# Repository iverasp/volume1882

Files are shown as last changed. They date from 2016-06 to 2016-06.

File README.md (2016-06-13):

## Storing the wiper positions

The DS1882 has an internal EEPROM which can store the wiper positions. However, it will write to the EEPROM on all volume changes, which will quickly wear out the memory.

We therefore store the wiper positions in the Atmega328p EEPROM instead. This EEPROM is said to survive 100 000 writes. To avoid writing to the EEPROM on all volume changes, we wait until the user has let the rotary encoder untouched for 3 seconds.
At an estimate of 10 volume changes per day in average, this lets the EEPROM survive for at least 27 years.

## DS1882 address

A2, A1 and A0 on the DS1882 are tied to ground.
The address of the device therefore becomes 40 (00101000 in binary).

## BOM

All passive SMD parts are of package 1206

Electrolytic capacitors: 2x0.1uF + 1uF + 10uF. Designed for 5mm diameter (Nichicon KW/FG).  
SMD capacitors: 3x0.1uF ceramic  
SMD resistors: 560R, 120R, 240R, 1k1, 2x4k7, 3x10k, 3x470R  
Voltage regulators: LM337 and LM317, SOT-223 packages  
Diodes: 1N4002 through hole  
ICs: DS1882 SOIC16 and ATmega328p TQFP-32  
Male headers: 1pcs 1x5 pins, 2pcs 1x4 pins, 4pcs 1x3 pins, 1pcs 1x2 pins, 1pcs 2x3 pins

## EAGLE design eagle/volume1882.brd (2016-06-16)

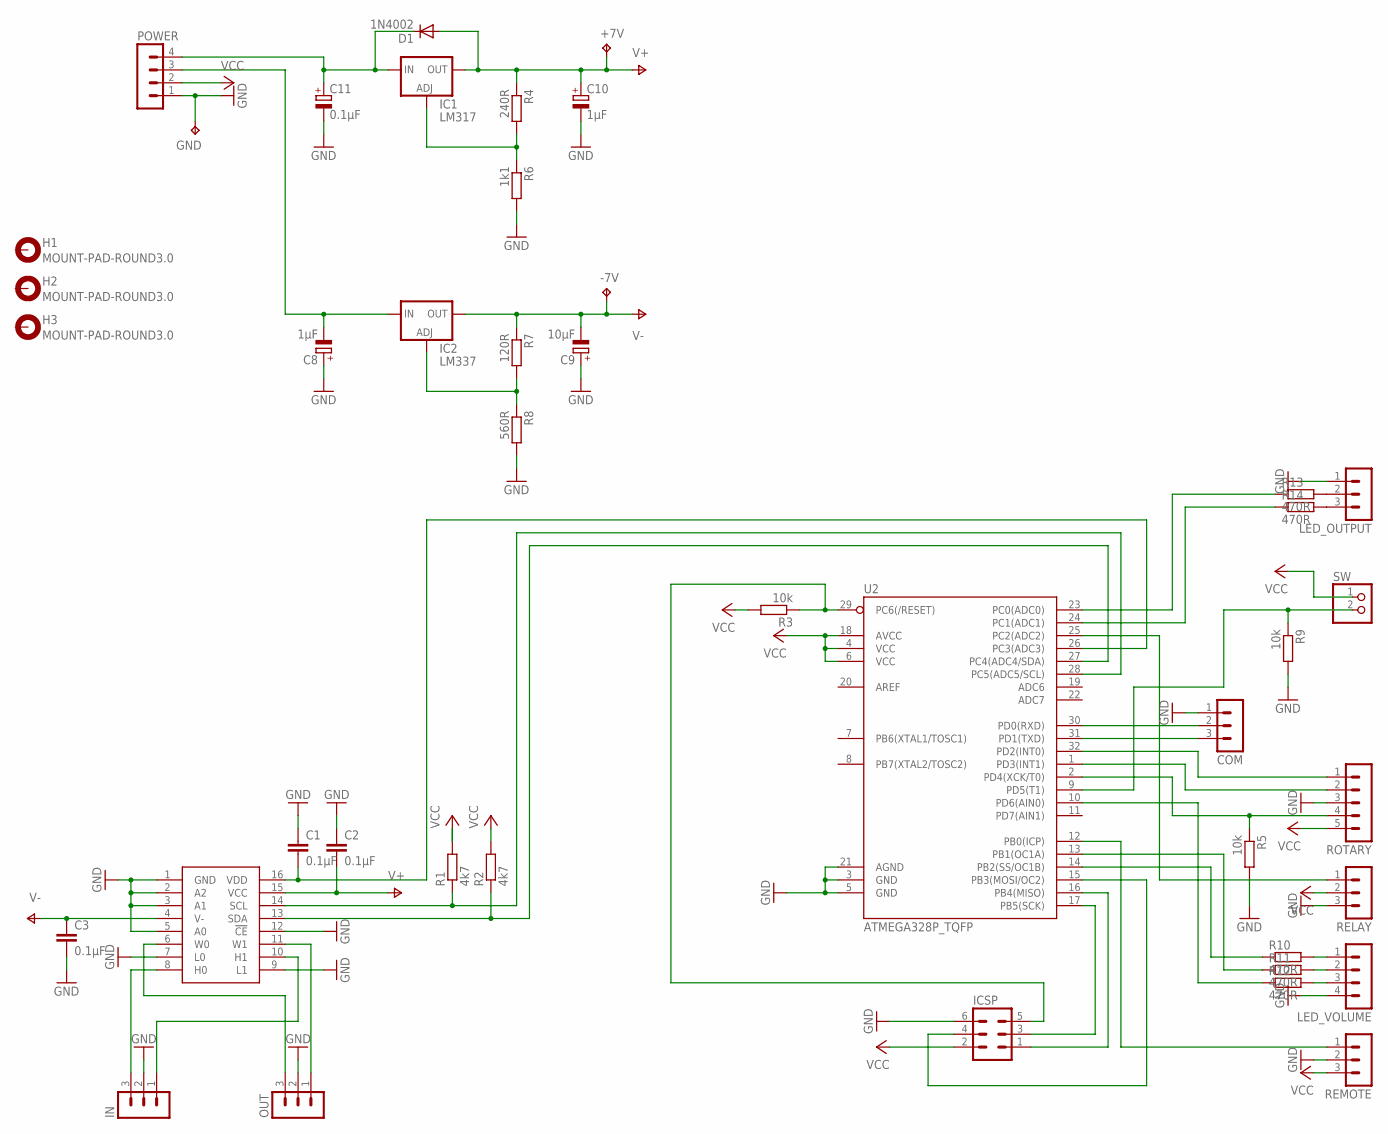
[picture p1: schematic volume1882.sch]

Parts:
+7V: TPTP12SQ; TP12SQ
-7V: TPTP12SQ; TP12SQ
C1, C2, C3: 0.1µF; C1206
C8, C10: 1µF; E2-5
C9: 10µF; E2-5
C11: 0.1µF; E2-5
COM: MA03-1
D1: 1N4002; DO41-10
GND: TPTP12SQ; TP12SQ
H1, H2, H3: MOUNT-PAD-ROUND3.0; 3,0-PAD
IC1: LM317; SOT223
IC2: LM337; SOT223
ICSP: MA03-2
IN: MA03-1
LED_OUTPUT: MA03-1
LED_VOLUME: MA04-1
OUT: MA03-1
POWER: MA04-1
R1, R2: 4k7; R1206
R3, R5, R9: 10k; R1206
R4: 240R; R1206
R6: 1k1; R1206
R7: 120R; R1206
R8: 560R; R1206
R10, R11, R12, R13, R14: 470R; R1206
RELAY: MA03-1
REMOTE: MA03-1
ROTARY: MA05-1
SW: PINHD-1X2; 1X02
U1: DS1882; SO16
U2: ATMEGA328P_TQFP; TQFP32-08

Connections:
GND: C1.1, C2.1, C3.2, C8.+, C9.+, C10.-, C11.-, COM.1, GND.TP, ICSP.6, IN.2, LED_OUTPUT.1, LED_VOLUME.4, OUT.2, POWER.1, R5.2, R6.2, R8.2, R9.2, RELAY.3, REMOTE.2, ROTARY.3, U1.1 (GND), U1.2 (A2), U1.3 (A1), U1.5 (A0), U1.7 (L0), U1.9 (L1), U1.12 (!CE), U2.3 (GND), U2.5 (GND), U2.21 (AGND)
unnamed: ICSP.5, R3.1, U2.29 (PC6(/RESET))
unnamed: ICSP.1, U2.16 (PB4(MISO))
unnamed: ICSP.3, U2.17 (PB5(SCK))
unnamed: ICSP.4, U2.15 (PB3(MOSI/OC2))
unnamed: R1.1, U1.14 (SCL), U2.28 (PC5(ADC5/SCL))
unnamed: R2.1, U1.13 (SDA), U2.27 (PC4(ADC4/SDA))
unnamed: COM.3, U2.31 (PD1(TXD))
unnamed: COM.2, U2.30 (PD0(RXD))
unnamed: ROTARY.1, U2.32 (PD2(INT0))
unnamed: ROTARY.2, U2.1 (PD3(INT1))
unnamed: R5.1, ROTARY.4, U2.2 (PD4(XCK/T0))
unnamed: C1.2, U1.16 (VDD), U2.26 (PC3(ADC3))
unnamed: R11.1, U2.13 (PB1(OC1A))
unnamed: R10.1, U2.14 (PB2(SS/OC1B))
unnamed: R12.1, U2.10 (PD6(AIN0))
unnamed: IN.3, U1.8 (H0)
unnamed: IN.1, U1.10 (H1)
unnamed: OUT.3, U1.6 (W0)
unnamed: OUT.1, U1.11 (W1)
unnamed: C11.+, D1.C, IC1.3 (IN), POWER.4
unnamed: C8.-, IC2.2 (IN), POWER.3
unnamed: IC1.1 (ADJ), R4.2, R6.1
unnamed: R9.1, SW.2, U2.9 (PD5(T1))
unnamed: IC2.1 (ADJ), R7.2, R8.1
unnamed: RELAY.1, U2.25 (PC2(ADC2))
unnamed: LED_VOLUME.1, R10.2
unnamed: LED_VOLUME.2, R11.2
unnamed: LED_VOLUME.3, R12.2
unnamed: R13.1, U2.23 (PC0(ADC0))
unnamed: R14.1, U2.24 (PC1(ADC1))
unnamed: LED_OUTPUT.2, R13.2
unnamed: LED_OUTPUT.3, R14.2
unnamed: REMOTE.1, U2.12 (PB0(ICP))
V+: +7V.TP, C2.2, C10.+, D1.A, IC1.4 (OUT), R4.1, U1.15 (VCC)
V-: -7V.TP, C3.1, C9.-, IC2.3 (OUT), R7.1, U1.4 (V-)
VCC: ICSP.2, POWER.2, R1.2, R2.2, R3.2, RELAY.2, REMOTE.3, ROTARY.5, SW.1, U2.4 (VCC), U2.6 (VCC), U2.18 (AVCC)

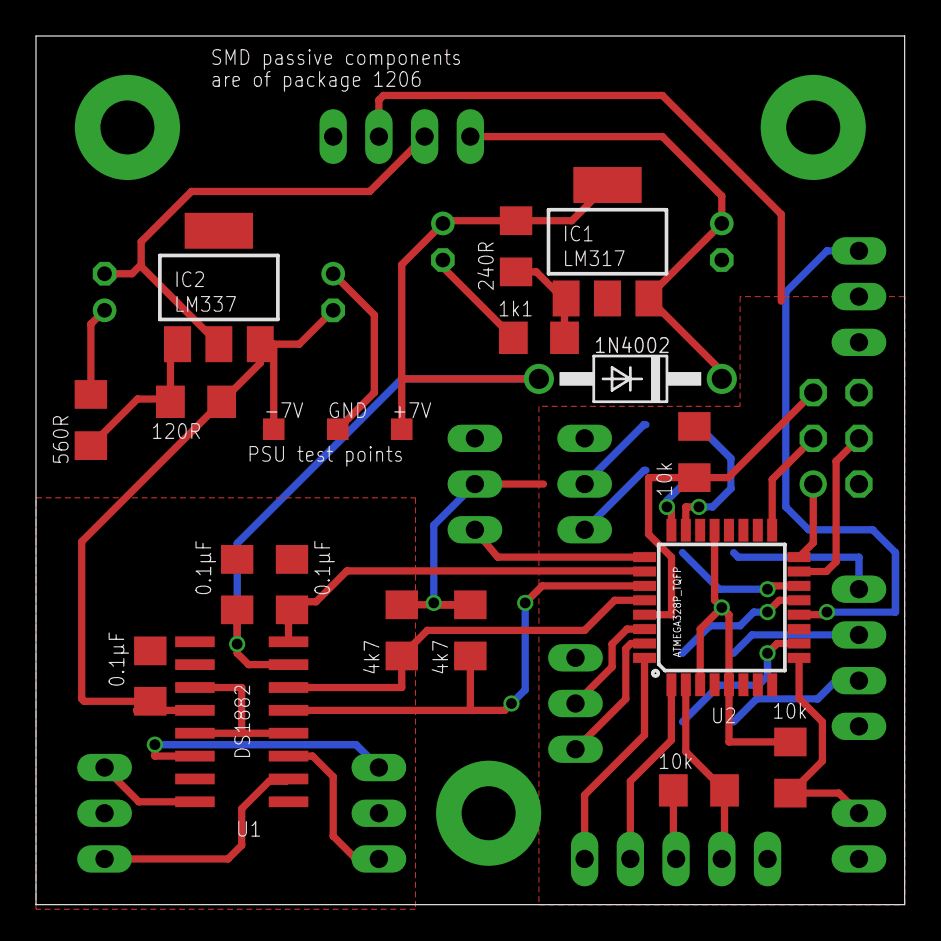
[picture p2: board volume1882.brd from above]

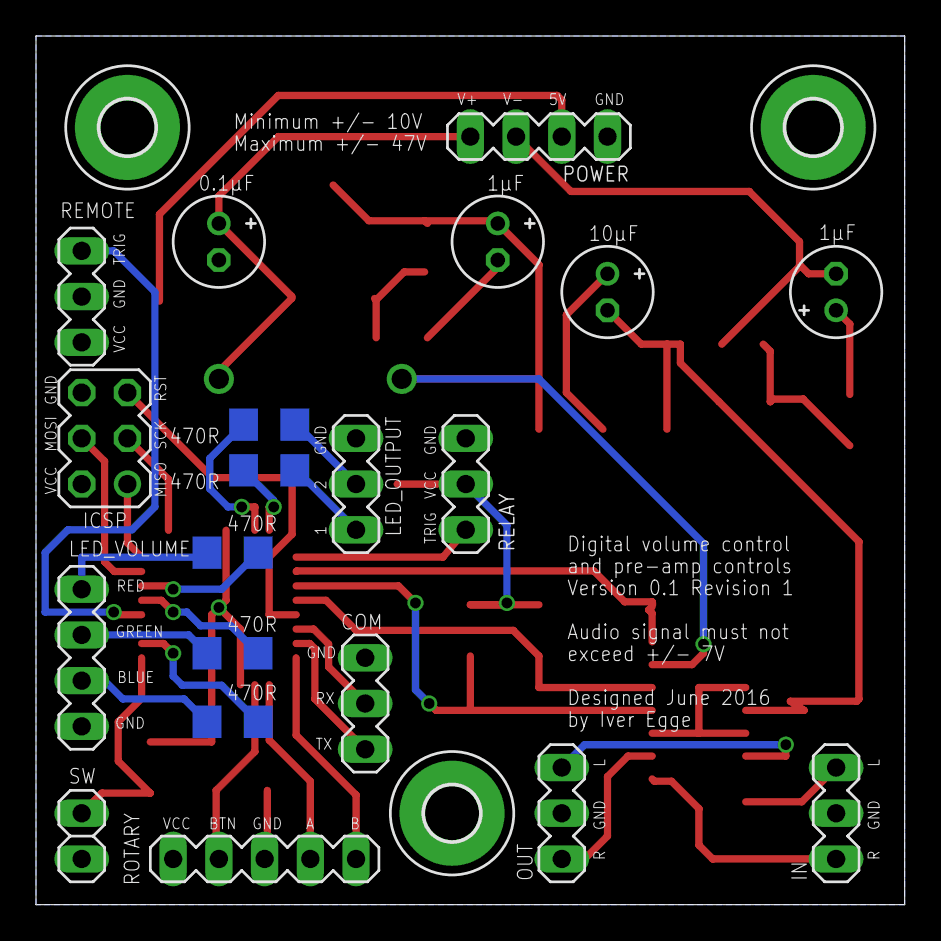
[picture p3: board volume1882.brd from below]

Board: 2 copper layers, 48.3 x 48.3 mm, 43 parts (23 on the bottom side), 37 nets.

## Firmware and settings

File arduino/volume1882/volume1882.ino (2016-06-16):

#include <Wire.h>
#include <Encoder.h>
#include <EEPROM.h>

const short red = 9; // pwm
const short green = 10; // pwm
const short potVdd = A3;
const short encA = 2; // interrupt
const short encB = 3; // interrupt
const int encMax = 62;
const short encDiv = 4; // encoder counts 4 steps per click
Encoder encoder(encB, encA);

const int muteButtonPin = 4;
int muteButtonState;
int lastMuteButtonState = LOW;
long lastMuteDebounceTime = 0;
long debounceDelay = 50;

const int outputSelectPin = 7;
int outputSelectState;
int lastOutputSelectState;
long lastOutputSelectDebounceTime = 0;
const int outputRelayPin = 8;
const int headphonesOutput = 0;
const int powerampOutput = 1;

bool mute = false;
byte muteAddress = 0;
byte attenuationAddress = 1;
byte headphonesMuteAddress = 0;
byte headphonesAttenuationAddress = 1;
byte powerampMuteAddress = 2;
byte powerampAttenuationAddress = 3;
byte lastAttenuation;
byte muteAttenuation = 63;
byte fadeStart = 50;
byte fadeStep = fadeStart;
byte fadeAmount = 5;

// A0, A1, A2 of DS1882 are shorted to ground
const byte potAddress = B0101000;
const byte potConfig = B10000110; // volatile memory, zero-crossing detection, 63 positions 

unsigned long attenuationChangeTimer = 0;
unsigned long startTime = 0;
unsigned long attenuationChangeTimeout = 2000;
byte lastStoredAttenuation = 0;

void setup() {
  pinMode(red, OUTPUT);
  pinMode(green, OUTPUT);
  delay(300); // wait for Vcc on DS1882 to stabilize
  pinMode(potVdd, OUTPUT);
  digitalWrite(potVdd, HIGH);
  
  //Serial.begin(9600);
  //Serial.println("Starting execution");
  
  Wire.begin();
  //TWBR = 12; // Sets i2c speed to 400kHz (max)
  Wire.beginTransmission(potAddress);
  byte error = Wire.endTransmission();
  if (error == 0) {
    //Serial.print("DS1882 found at address ");
    //Serial.println(potAddress);
  }
  Wire.requestFrom(potAddress, 3); // read pot0, pot1 and config
  byte pot1, pot2, conf;
  while (Wire.available()) {
    pot1 = Wire.read();
    pot2 = Wire.read();
    conf = Wire.read();
  }
  if (conf != potConfig) {
    //Serial.println("DS1882 config is incorrect. Uploading correct config...");
    Wire.beginTransmission(potAddress);
    Wire.write(potConfig);
    byte error = Wire.endTransmission();
    //Serial.println(error);
  }

  pinMode(outputSelectPin, INPUT);
  int lastOutputSelectState = digitalRead(outputSelectPin);
  pinMode(outputRelayPin, OUTPUT);
  selectOutput(digitalRead(outputSelectPin));
}

void loop() {
  if (!mute) {
    long value = readEncoder();
    analogWrite(red, ((((value+2) * 4) - 255)*-1)+1);
    analogWrite(green, value * 4);
    if (value != lastAttenuation) {
      adjustAttenuation(value);
      attenuationChangeTimer = millis();
    }
    if (millis() - attenuationChangeTimer > attenuationChangeTimeout) {
      storeAttenuation(value);
    }
  } else {
    analogWrite(red, fadeStep);
    analogWrite(green, (fadeStep - 255)*-1);
    fadeStep += fadeAmount;
    if (fadeStep < fadeStart || fadeStep > 200) {
      fadeAmount = -fadeAmount;
    }
    delay(30);
  }
  readMuteButton();
  readToggleSwitch();
}

long readEncoder() {
  long value = encoder.read();
  if (value > encMax * encDiv) {
    encoder.write(encMax * encDiv);
    return encMax;
  }
  if (value < 0) {
    encoder.write(0);
    return 0;
  }
  return value / encDiv;
}

void readMuteButton() {
  int reading = digitalRead(muteButtonPin);
  if (reading != lastMuteButtonState) {
    lastMuteDebounceTime = millis();
  }
  if ((millis() - lastMuteDebounceTime) > debounceDelay) {
    if (reading != muteButtonState) {
      muteButtonState = reading;
      if (muteButtonState == HIGH) {
        toggleMute();
      }
    }
  }
  lastMuteButtonState = reading;
}

void readToggleSwitch() {
  int reading = digitalRead(outputSelectPin);
  if (reading != lastOutputSelectState) {
    lastOutputSelectDebounceTime = millis();
  }
  if ((millis() - lastOutputSelectDebounceTime) > debounceDelay) {
    if (reading != outputSelectState) {
      outputSelectState = reading;
      selectOutput(outputSelectState);
    }
  }
  lastOutputSelectState = reading;
}

void toggleMute() {
  mute = !mute;
  if (EEPROM.read(muteAddress) != mute) {
    EEPROM.write(muteAddress, mute);
  }
  fadeStep = fadeStart;
  if (mute) {
    storeAttenuation(readEncoder());
    adjustAttenuation(muteAttenuation);
  } else {
    encoder.write(lastAttenuation * encDiv);
    adjustAttenuation(readEncoder());
  }
}

void adjustAttenuation(long value) {
  if (value != muteAttenuation) {
    lastAttenuation = value;
    //Serial.print("Adjusting attenuation to ");
    //Serial.print(value);
    //Serial.println(" dB");
  } else {
    //Serial.println("Muting");
  }

  Wire.beginTransmission(potAddress);
  Wire.write(value);
  Wire.endTransmission();
  Wire.beginTransmission(potAddress);
  Wire.write(value | B01000000);
  Wire.endTransmission();

}

void storeAttenuation(long value) {
  if (lastStoredAttenuation != value) {
    //Serial.println("Saving attenuation value to EEPROM...");
    EEPROM.write(attenuationAddress, value);
    lastStoredAttenuation = value;
  }
}

void selectOutput(byte output) {
  storeAttenuation(readEncoder());
  if (output == 0) {
    //Serial.println("Switching output to headphones");
    muteAddress = headphonesMuteAddress;
    attenuationAddress = headphonesAttenuationAddress;
  } else if (output == 1) {
    //Serial.println("Switching output to poweramp");
    muteAddress = powerampMuteAddress;
    attenuationAddress = powerampAttenuationAddress;
  }
  digitalWrite(outputRelayPin, output);
  setInitialValues();
}

void setInitialValues() {
  mute = EEPROM.read(muteAddress);
  byte currentAttenuation = EEPROM.read(attenuationAddress);
  encoder.write(currentAttenuation * encDiv);
  lastAttenuation = currentAttenuation;
  lastStoredAttenuation = currentAttenuation;
  if (mute) {
    adjustAttenuation(muteAttenuation);
  } else {
    adjustAttenuation(currentAttenuation);
  }
}

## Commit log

2016-06-06 two settings for either poweramp or headphone amp
2016-06-12 output select switch
    [volume1882.sch]
2016-06-13 finished board
    [volume1882.brd, volume1882.sch]
2016-06-14 fixed wrong size parts
    [volume1882.brd, volume1882.sch]
2016-06-16 small fixes
    [volume1882.brd, volume1882.sch]

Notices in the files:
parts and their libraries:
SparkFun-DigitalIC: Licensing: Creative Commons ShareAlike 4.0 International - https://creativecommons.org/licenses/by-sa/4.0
